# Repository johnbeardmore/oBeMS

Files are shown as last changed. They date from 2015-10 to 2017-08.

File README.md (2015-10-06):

oBeMS
=====

Open source environmental monitoring, automatic meter reading and building management system.

Note that the items in [square brackets] below are planned, but not yet implemented.

Open Source GPL2 system for energy and environmental measurement, automatic meter reading (AMR), [building energy management (BEMS), and building management (BMS)].

The system consists of server processes which provide access to sensors and actuators via IP address and port number. Server processes are used which provide user interfaces, [make BMS and BEMS decisions], and relay information to archival stores.

An archival store is provided to record environmental conditions, [and BMS and BEMS decisions].

Modules can be distributed around the internet, and in this sense it may be seen as part of the Internet Of Things (IoT).

Initial development has mostly taken place on the Raspberry Pi under Raspbian, though it should port perfectly well to other linux based boards, e.g. the BeagleBone.

The archival database has been implemented on an Intel Linux box to avoid doing frequent writes to SD cards.

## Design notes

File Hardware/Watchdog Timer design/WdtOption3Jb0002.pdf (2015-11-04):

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

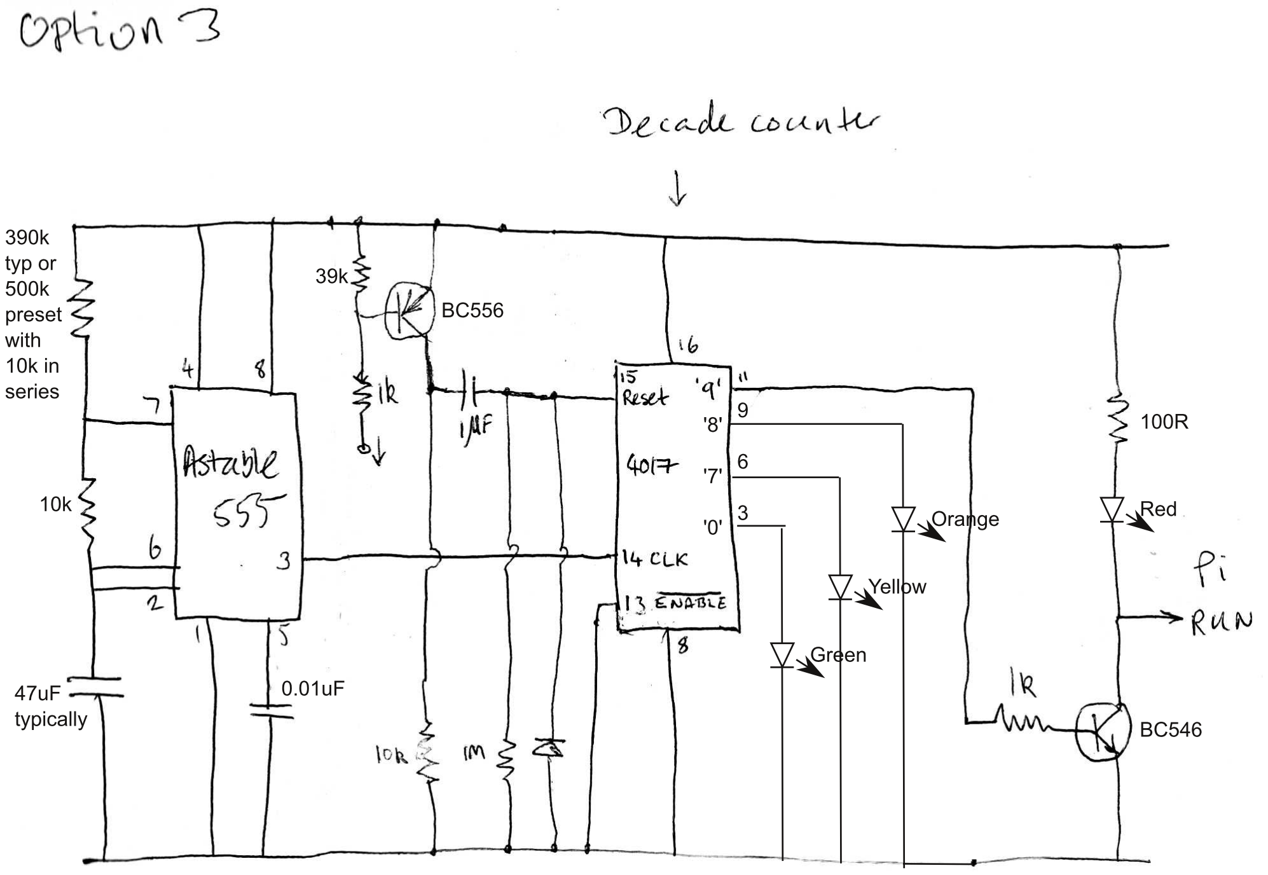
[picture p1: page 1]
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

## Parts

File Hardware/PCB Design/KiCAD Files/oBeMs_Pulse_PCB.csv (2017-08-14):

Reference | Quantity | Value | Footprint | Datasheet | Description | Manufacturer | Manufacturer Part No | Supplier 1 | Supplier 1 Part No | Notes | Supplier 2 | Supplier 2 Part No
C1 C10 | 2 | 100u | REInnovationFootprint:C2V8_VandA |  | Value | Value | Value | Value | Value | Value | Value | Value
C11 C2 | 2 | 1000u | REInnovationFootprint:C2V8_VandA |  | Value | Value | Value | Value | Value | Value | Value | Value
C3 | 1 | 1u | matts_components:C1_wide_lg_pad_2
C4 | 1 | 0.1u | matts_components:C1_wide_lg_pad_2
C5 | 1 | 10n | matts_components:C1_wide_lg_pad_2
C6 | 1 | 47u | REInnovationFootprint:C2V8_VandA
C7 C8 | 2 | 1000n | matts_components:C1_wide_lg_pad_2 |  | Value | Value | Value | Value | Value | Value | Value | Value
C9 | 1 | 100n | matts_components:C1_wide_lg_pad_2 |  | Value | Value | Value | Value | Value | Value | Value | Value
CPU1 | 1 | RPi_B | REInnovationFootprint:RPi_B_B+_MOUNTING
D12 | 1 | GRN | REInnovationFootprint:LED-5MM_larg_pad
D13 | 1 | YEL | REInnovationFootprint:LED-5MM_larg_pad |  | Value | Value | Value | Value | Value | Value | Value | Value
D14 | 1 | ORG | REInnovationFootprint:LED-5MM_larg_pad
D1 D15 | 2 | 1N5822 | REInnovationFootprint:TH_Diode_DO-201AD |  | 3A 40V Shottky Diode | STMicroelectronics | 1N5822 | RS | 687-0877
D16 | 1 | BRIDGE | REInnovationFootprint:TH_BridgeRect_8A | http://docs-europe.electrocomponents.com/webdocs/1404/0900766b81404e75.pdf | 8A Bridge Rectifier | Taiwan Semiconductor | KBU807G | RS | 687-5914
D2 | 1 | 1N4001 | REInnovationFootprint:TH_Diode_1
D3 | 1 | RED | REInnovationFootprint:LED-5MM_larg_pad
D10 D11 D4 D5 D6 D7 D8 D9 | 8 | LED | REInnovationFootprint:LED-5MM_larg_pad
EN1 | 1 | Enclosure
F1 | 1 | 500mA | REInnovationFootprint:TH_Fuse_Holder_5-20_CPC | http://www.farnell.com/datasheets/1564551.pdf | 240V AC 5A Fuseholder | Unbranded | MCHTC-100M | CPC | FF01942
H1 H2 | 2 | AC Cover Mount Hole | REInnovationFootprint:3mm_hole
L1 | 1 | 330uH | REInnovationFootprint:TH_Inductor | http://docs-europe.electrocomponents.com/webdocs/0d90/0900766b80d90b31.pdf | Inductor. 1A RMS. | Panasonic | ELC11D331F | RS | 675-5428
L2 | 1 | 100uH | REInnovationFootprint:TH_Inductor_ELC18B101L | http://docs-europe.electrocomponents.com/webdocs/002b/0900766b8002b270.pdf | Inductor. 3A RMS. | Panasonic | ELC18B101L | RS | 233-5409
LG1 | 1 | REI Logo | matts_components:reinnovation_logo_15mm
LG2 | 1 | T4 Logo | PCB_logo:T4_32mm
LG3 | 1 | OSHW Logo | PCB_logo:OSHW_13mm
LG4 | 1 | V0000 |  |  | Value | Value | Value | Value | Value | Value | Value | Value
P1 | 1 | 1WIRE | REInnovationFootprint:Pin_Header_Straight_1x04
P10 | 1 | 5V | REInnovationFootprint:Pin_Header_Straight_2x08
P11 | 1 | 3V3 | REInnovationFootprint:Pin_Header_Straight_2x08
P12 | 1 | GND | REInnovationFootprint:Pin_Header_Straight_2x08
P13 | 1 | ADC_0-7 | REInnovationFootprint:Pin_Header_Straight_2x08
P14 | 1 | ADC_8-15 | REInnovationFootprint:Pin_Header_Straight_2x08
P15 | 1 | ADC_VREF_2 | REInnovationFootprint:Pin_Header_Straight_1x02
P16 | 1 | ADC_VREF_1 | REInnovationFootprint:Pin_Header_Straight_1x02
P17 | 1 | SPI_ADC_DAC | REInnovationFootprint:Pin_Header_Straight_1x08
P18 P22 P26 | 3 | DIO_OUTPUT | REInnovationFootprint:Pin_Header_Straight_2x12
P19 P23 P27 | 3 | PULL_UP | REInnovationFootprint:Pin_Header_Straight_2x12
P2 | 1 | EXT_CAP | matts_components:SIL-2_wide_lg_pad
P20 P24 P28 | 3 | GROUND | REInnovationFootprint:Pin_Header_Straight_2x12
P21 P25 P29 | 3 | DIO_INPUT | REInnovationFootprint:HEADER_12Way_Wiedermuller_SX | http://docs-europe.electrocomponents.com/webdocs/0fdb/0900766b80fdbcf2.pdf | 12 Way Pluggable Connector. SL 5.08 Series | Wiedermuller | 1511360000 | CPC | CN12535
P3 | 1 | HARD_WDT | REInnovationFootprint:TH_4x1_CONN
P30 | 1 | UNREG_DC | REInnovationFootprint:Pin_Header_Straight_2x03
P31 | 1 | V2? | REInnovationFootprint:SIL-3_solder_connect
P34 | 1 | DAC | REInnovationFootprint:Pin_Header_Straight_2x04
P36 | 1 | PROTOTYPING_AREA | REInnovationFootprint:PROTO_AREA_16x14
P4 | 1 | LED 5-8 | REInnovationFootprint:Pin_Header_Straight_1x04
P5 | 1 | AC_INPUT_PLUG |  | http://www.farnell.com/datasheets/1826287.pdf | 240V AC >3A PLUG | CamdenBoss | CTB9208/3 | CPC | CN11606
P6 | 1 | AC_INPUT | REInnovationFootprint:TH_3W_CamdenBoss | http://www.farnell.com/datasheets/1564536.pdf | 240V AC >3A | CamdenBoss | CTB9358/3 | CPC | CN11626
P7 | 1 | LED 1-4 | REInnovationFootprint:Pin_Header_Straight_1x04
P8 | 1 | LT_PWR | REInnovationFootprint:TH_CONN_2W
P9 | 1 | V1? | REInnovationFootprint:SIL-3_solder_connect
PCB1 | 1 | PCB | REInnovationFootprint:PCB_120x150_WISKA
PSU1 | 1 | PSU_10W_5V | REInnovationFootprint:TH_DCDC_PowerPac_5W_10W | http://www.farnell.com/datasheets/1683226.pdf | 240V AC to 5V PSU 5/10W 1/2A | Powerpax | PD05-20B05 | CPC | PW03300
Q1 | 1 | BC546 | matts_components:TO92-EBC_large_pad | http://docs-europe.electrocomponents.com/webdocs/078e/0900766b8078ea72.pdf | NPN. 1A. 80V | ON Semiconductor | BC639 | RS | 545-2276
Q2 | 1 | BC556 | matts_components:TO92-PNP_large_pad
R1 | 1 | 4k7 | REInnovationFootprint:TH_Resistor_1
R11 R12 R13 R14 R15 R16 R17 R18 R19 R20 R21 R22 R23 R24 R25 R26 R27 R28 R29 R30 R31 R32 R33 R34 R35 R36 R37 R38 R39 R40 R41 R42 R43 R44 R45 R46 R47 R48 R49 R50 R51 R52 R53 R54 | 44 | 120 | REInnovationFootprint:TH_Resistor_1 |  | Value | Value | Value | Value | Value | Value | Value | Value
R3 | 1 | 1M | REInnovationFootprint:TH_Resistor_1
R4 R7 | 2 | 1k | REInnovationFootprint:TH_Resistor_1
R5 | 1 | 39k | REInnovationFootprint:TH_Resistor_1
R6 | 1 | 100 | REInnovationFootprint:TH_Resistor_1 |  | Value | Value | Value | Value | Value | Value | Value | Value
R2 R8 R9 | 3 | 10k | REInnovationFootprint:TH_Resistor_1
RV1 | 1 | 500k | matts_components:RV_various_lg_pad
U1 | 1 | LM2575 | REInnovationFootprint:TO220_5PIN | http://docs-europe.electrocomponents.com/webdocs/0780/0900766b807800ee.pdf | 1A 3.3V DC DC converter IC | Texas Instruments | LM2575T-3.3/NOPB | RS | 533-3169
U2 | 1 | DS18B20 | REInnovationFootprint:TO92_DS18B20 | https://uk.rs-online.com/web/p/temperature-humidity-sensors/7860809/ | 1 Wire. Serial. Temperature sensor | Maxim | DS18B20+PAR | RS | 786-0809
U3 | 1 | TLC555 | REInnovationFootprint:DIP-8__300_ELL
U4 | 1 | 4017 | REInnovationFootprint:DIP-16__300_ELL_lg_pad
U5 U6 | 2 | MCP3008 | REInnovationFootprint:DIP-16__300_ELL_lg_pad
U7 | 1 | MCP4802 | REInnovationFootprint:DIP-8_300_ELL | http://ww1.microchip.com/downloads/en/DeviceDoc/22249A.pdf | 8 Bit Dual DAC | Microchip
U8 | 1 | LM2576 | REInnovationFootprint:TO220_5PIN | http://www.ti.com/lit/ds/symlink/lm2576.pdf |  | Texas Instruments | LM2576T-5.0/LF03 | RS | 460-477 | 3A step-down DC DC converter 5V

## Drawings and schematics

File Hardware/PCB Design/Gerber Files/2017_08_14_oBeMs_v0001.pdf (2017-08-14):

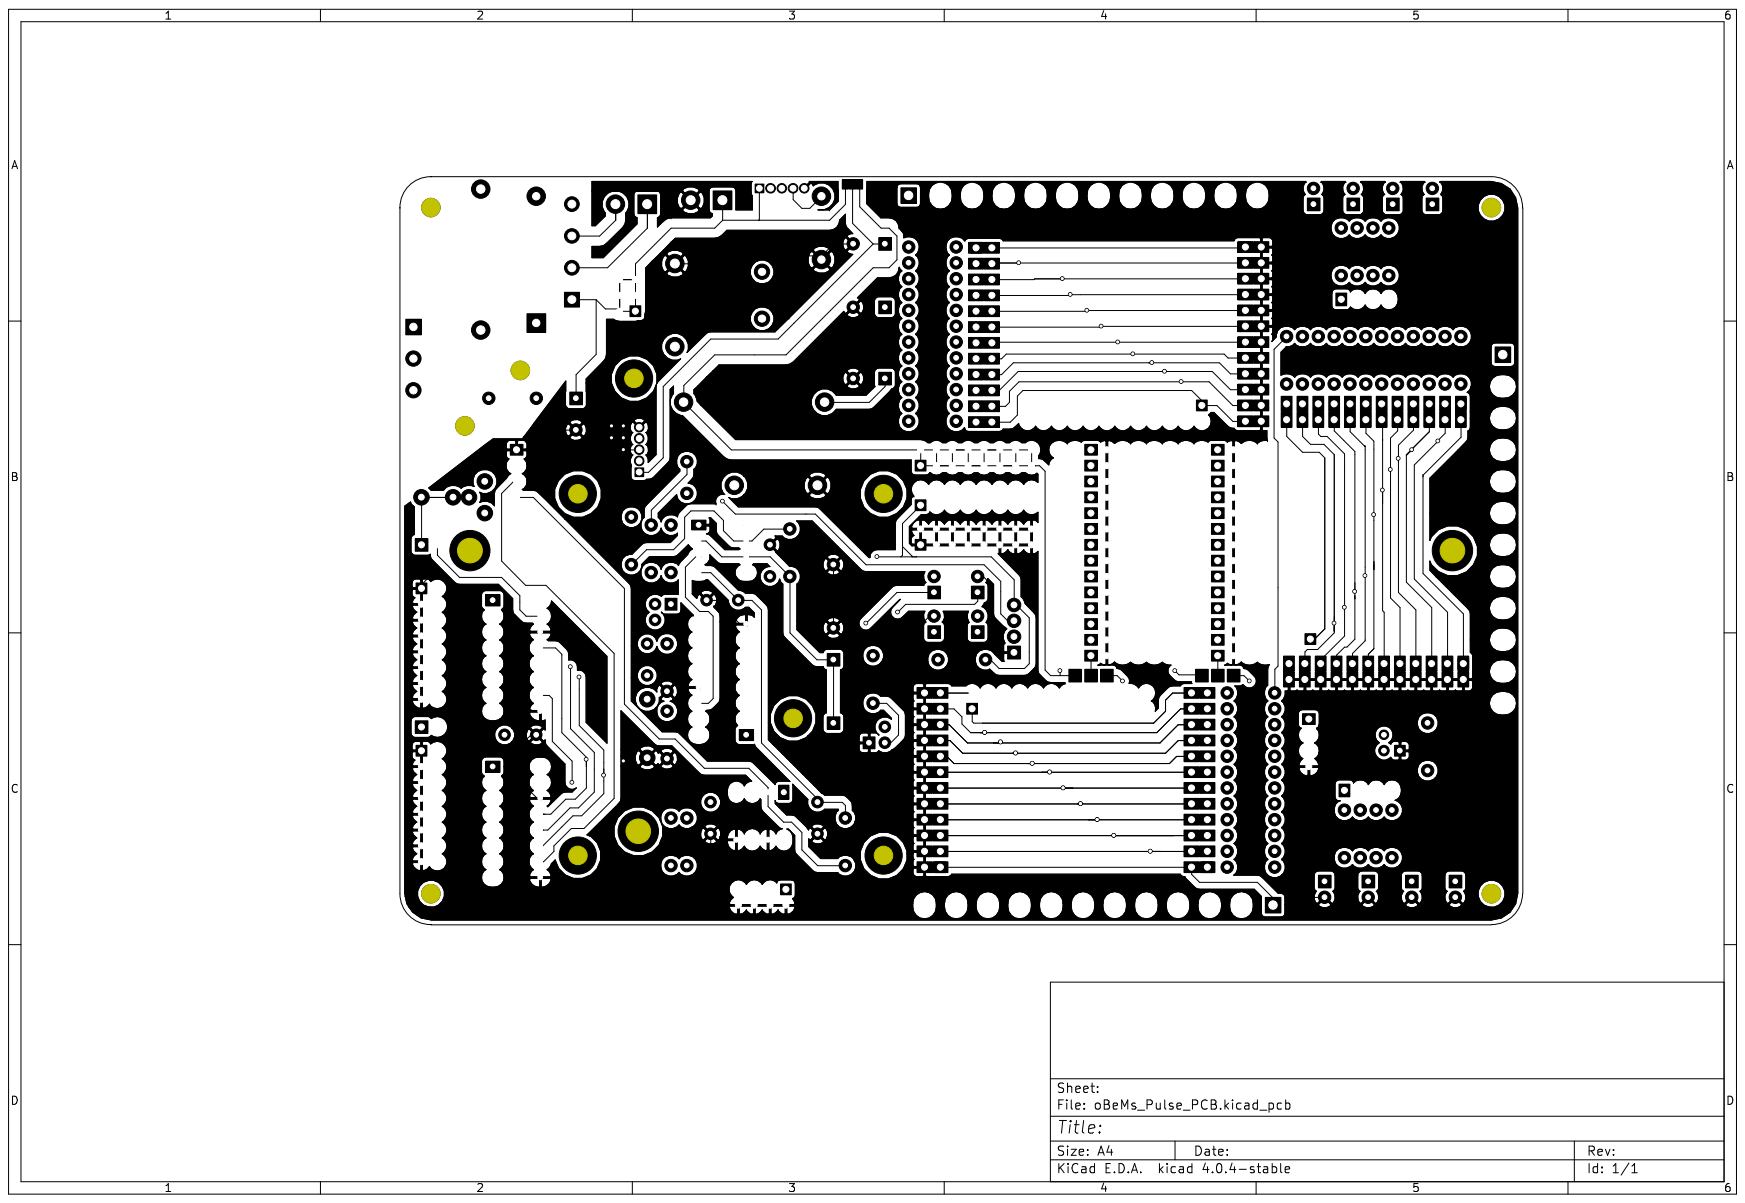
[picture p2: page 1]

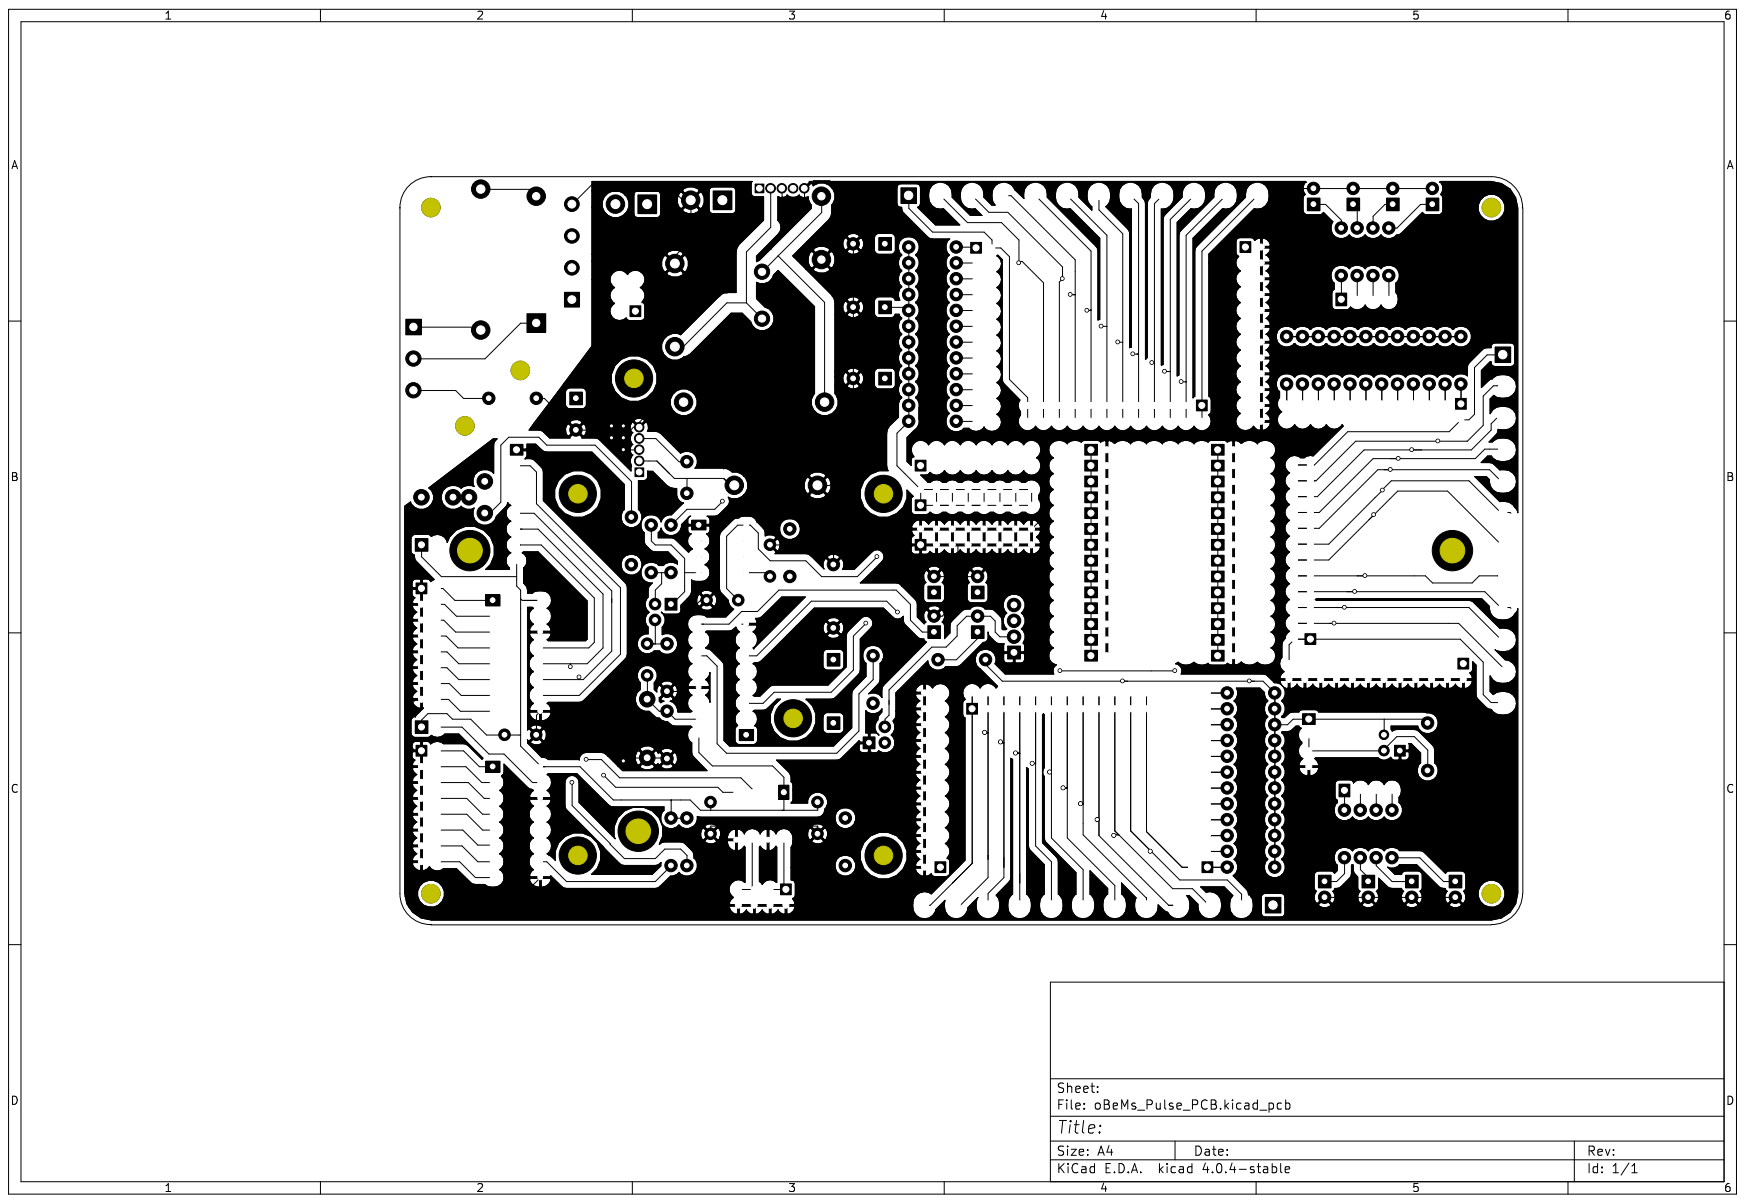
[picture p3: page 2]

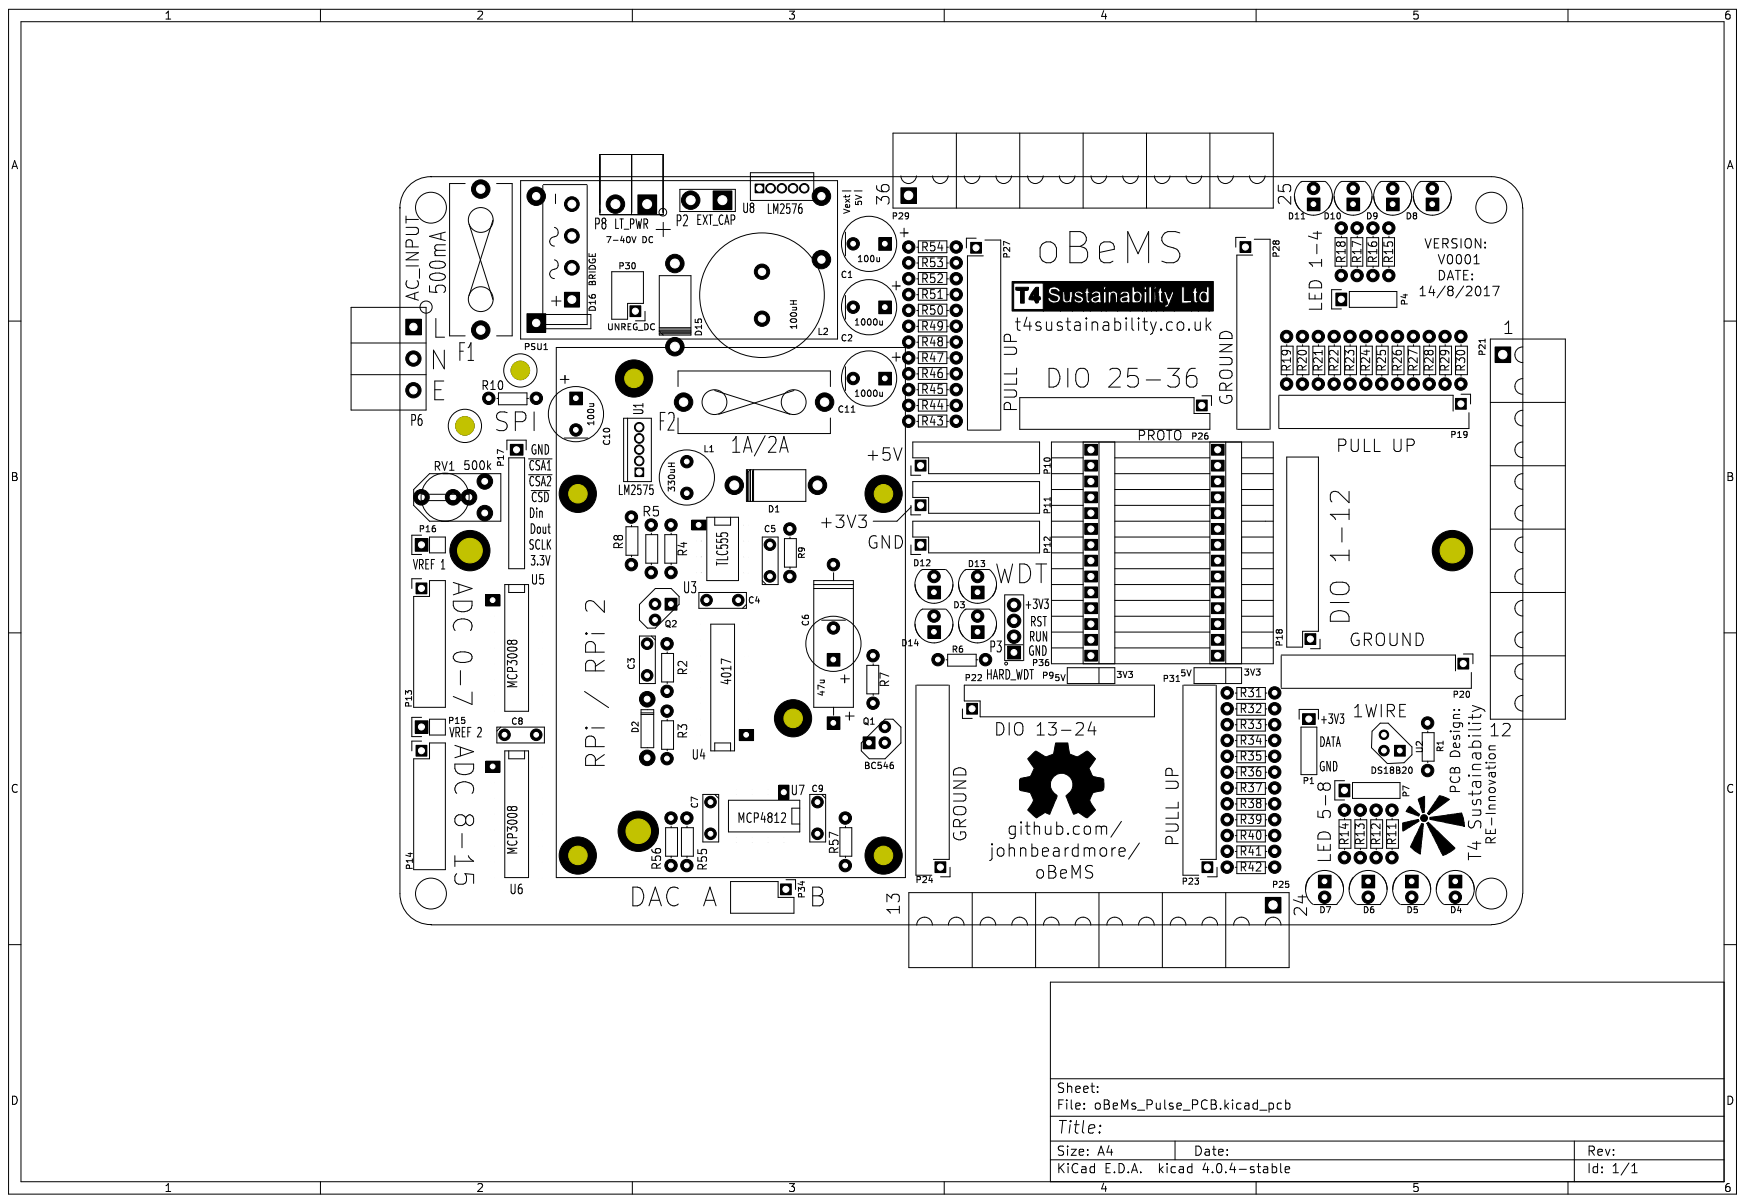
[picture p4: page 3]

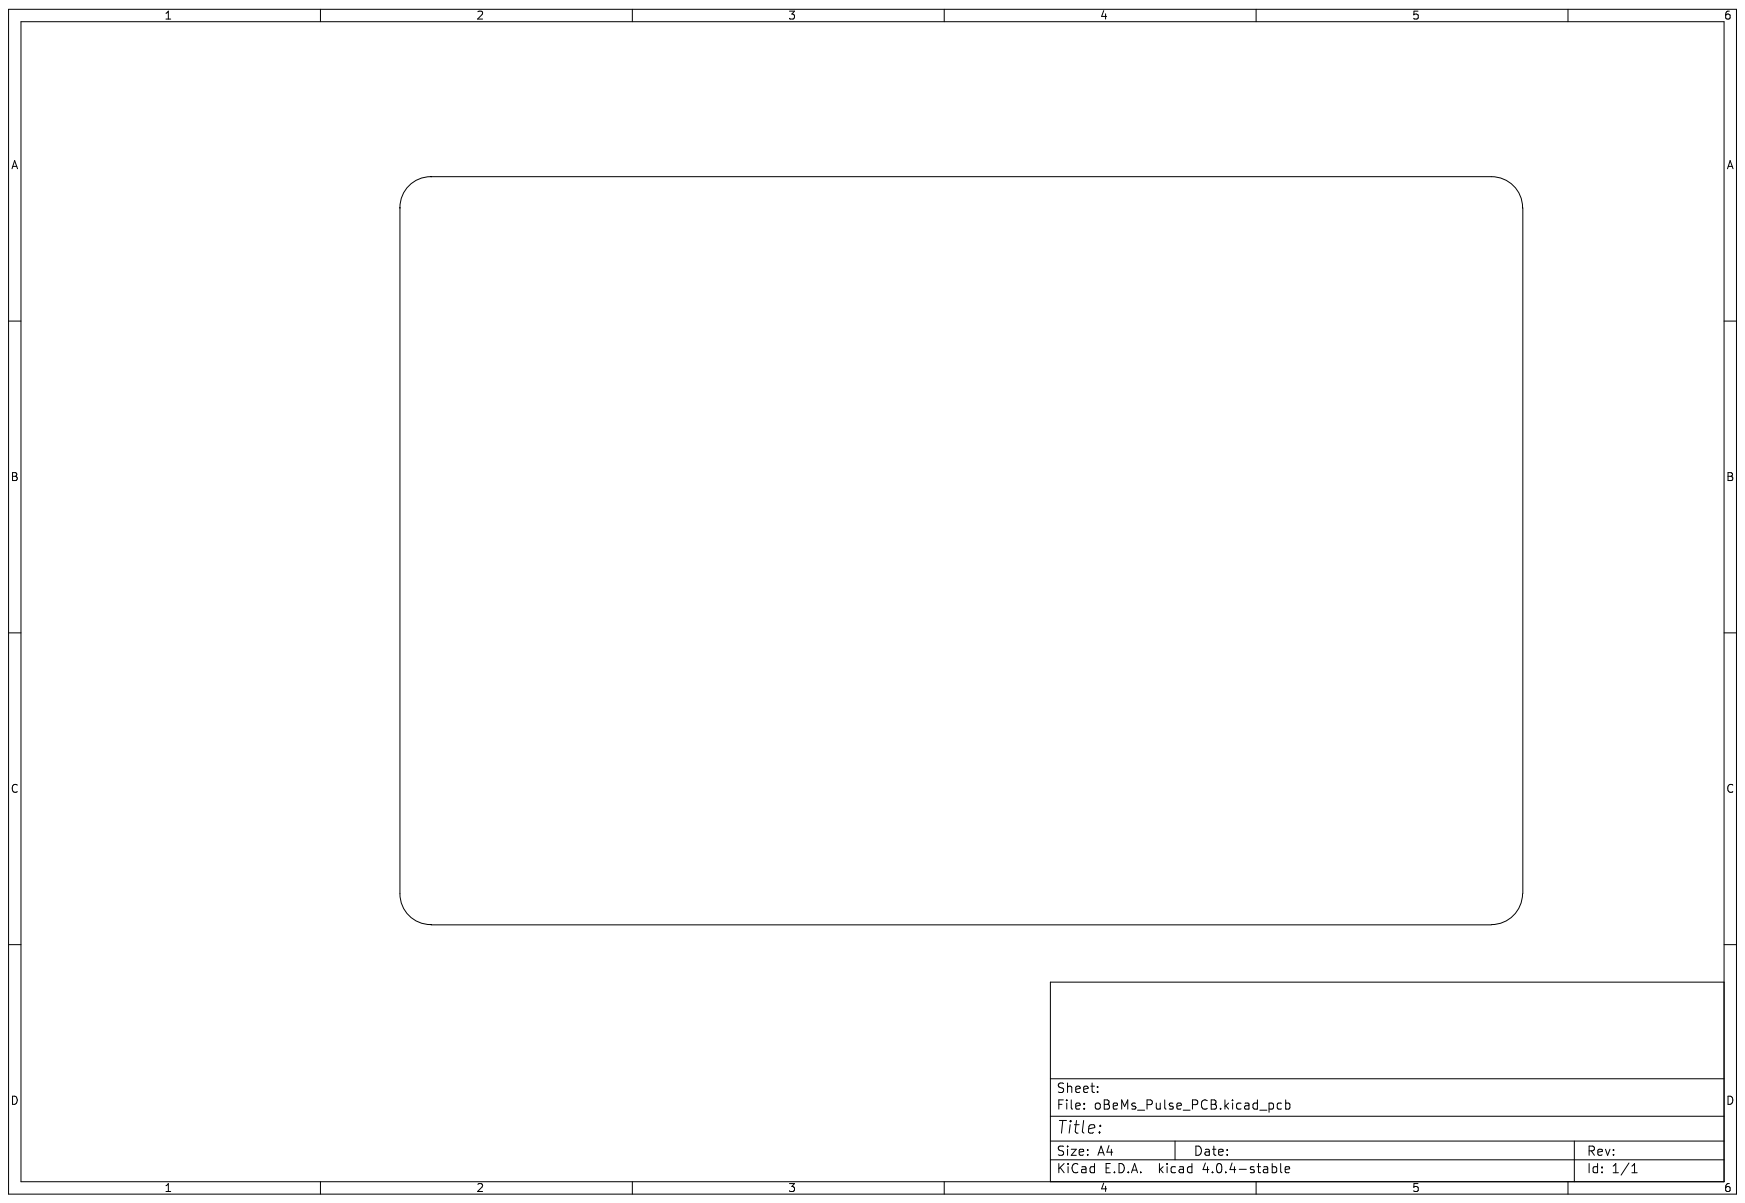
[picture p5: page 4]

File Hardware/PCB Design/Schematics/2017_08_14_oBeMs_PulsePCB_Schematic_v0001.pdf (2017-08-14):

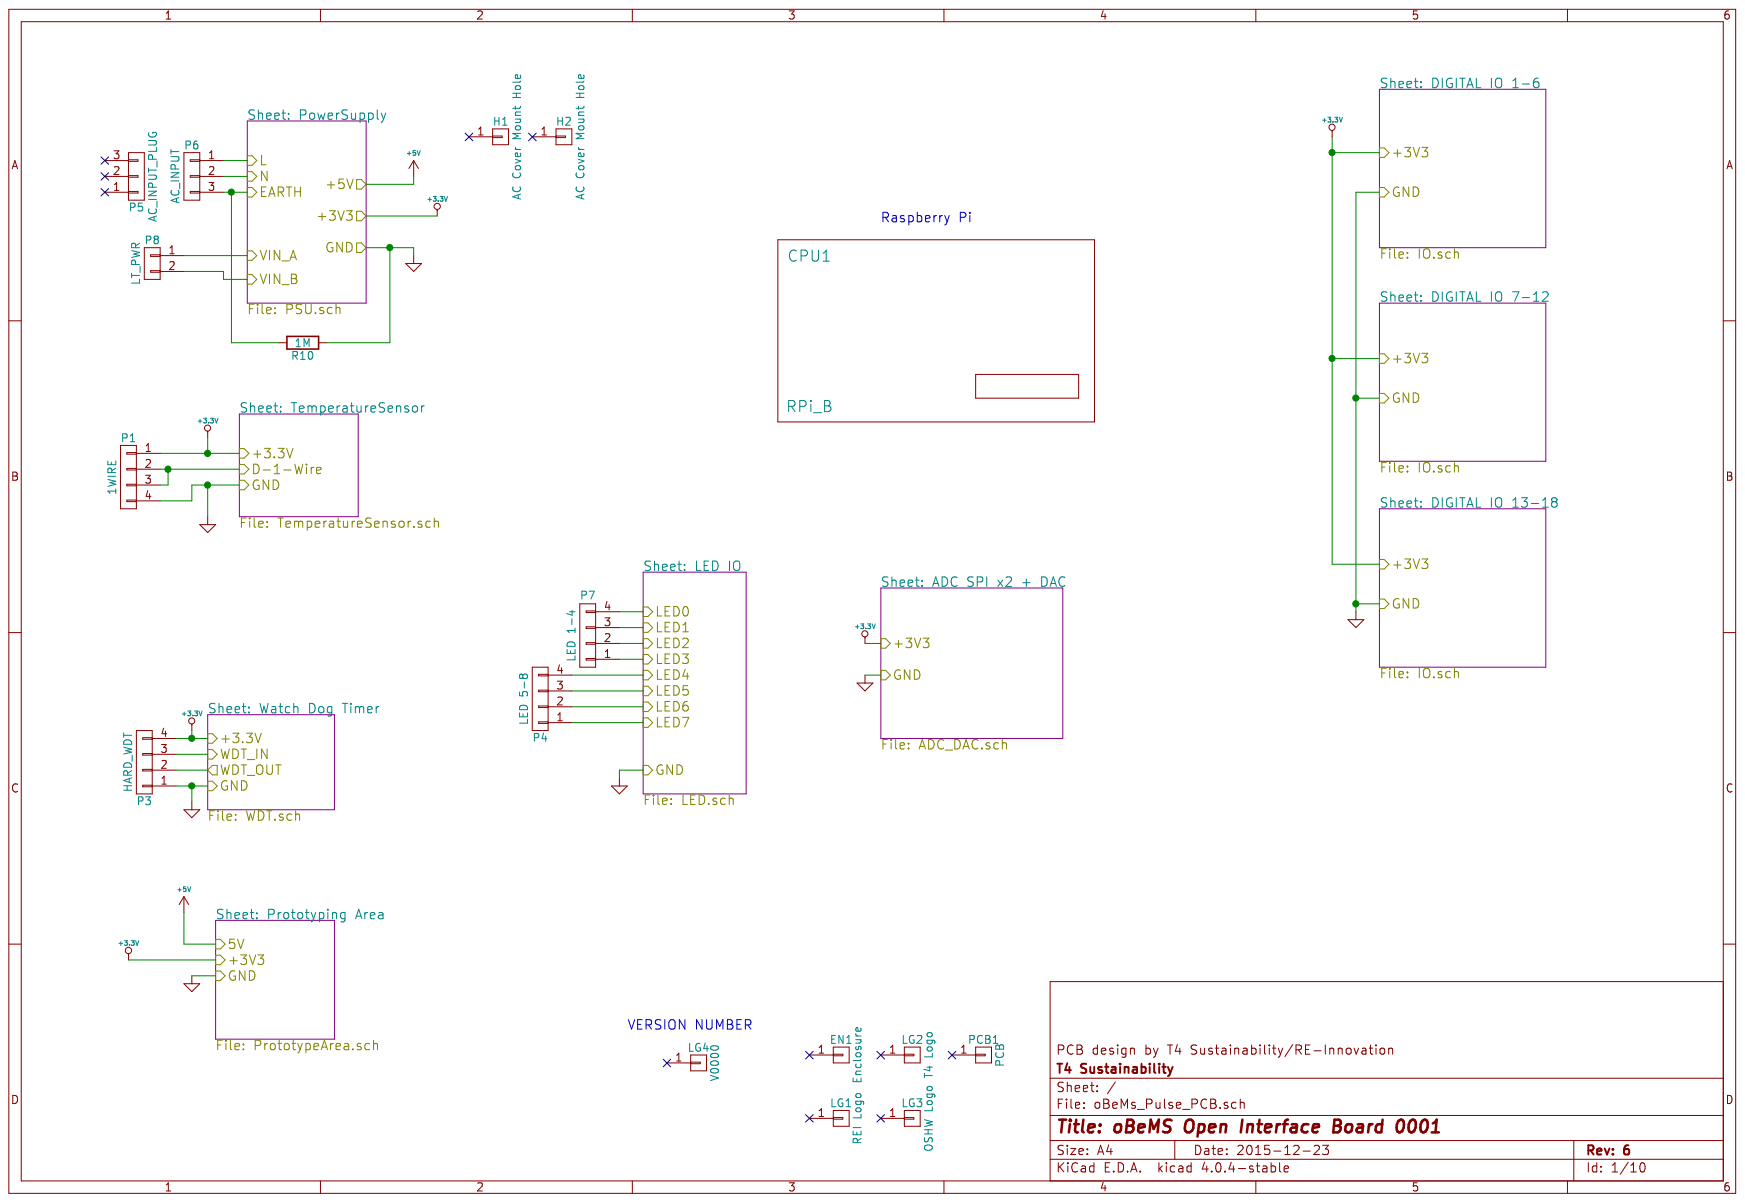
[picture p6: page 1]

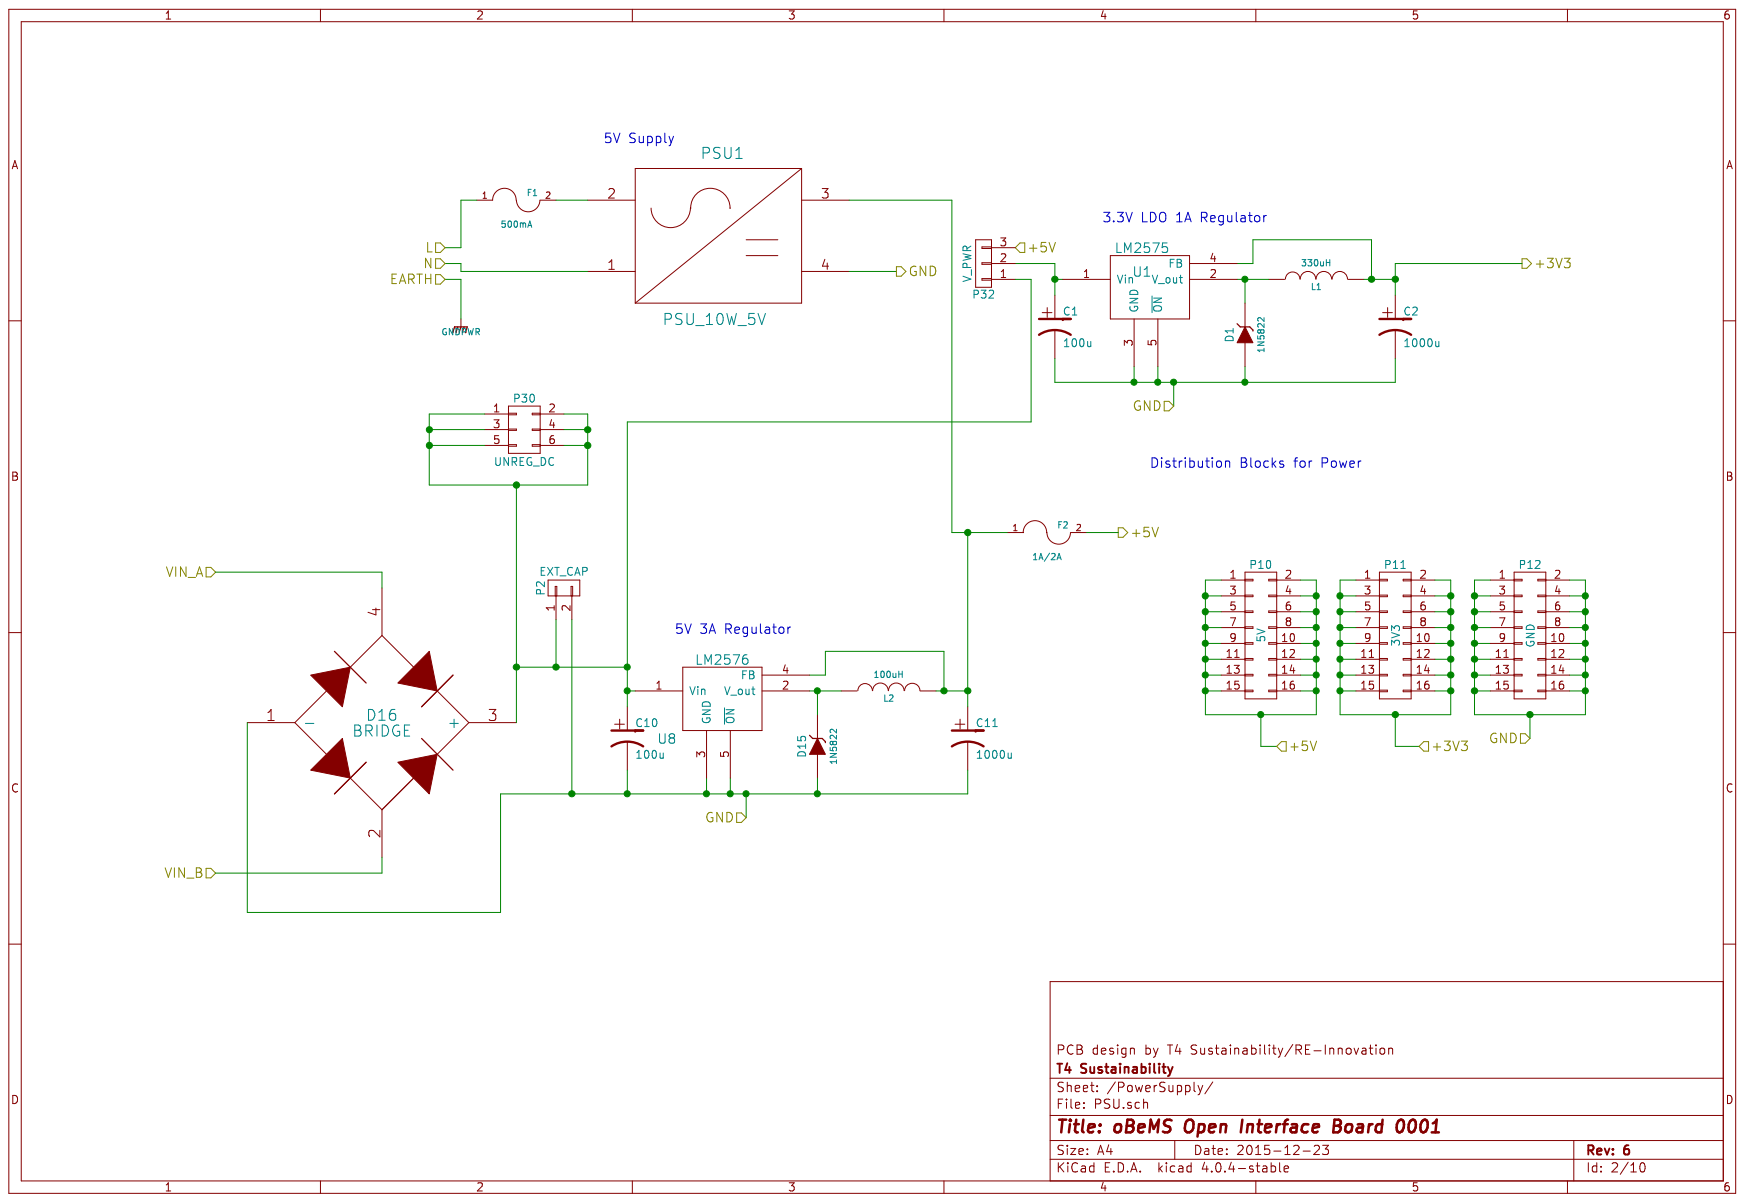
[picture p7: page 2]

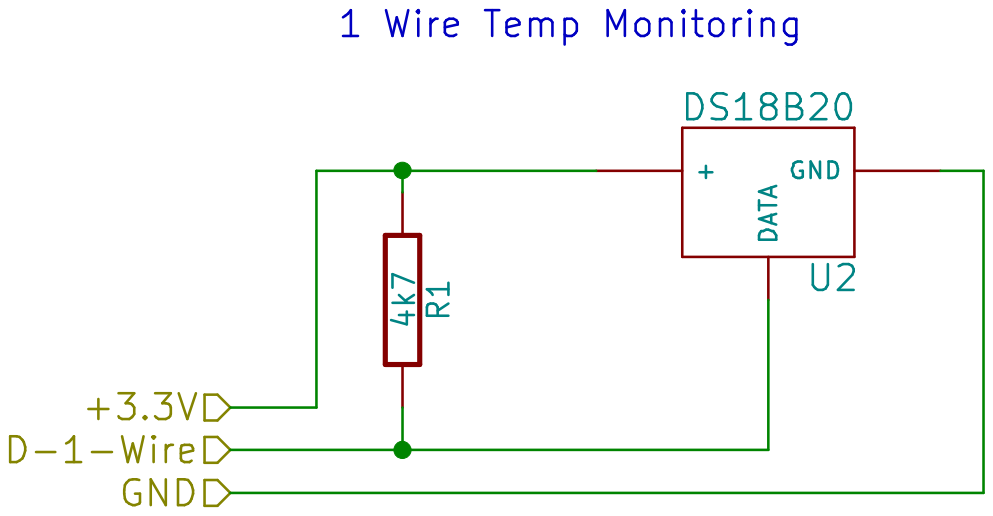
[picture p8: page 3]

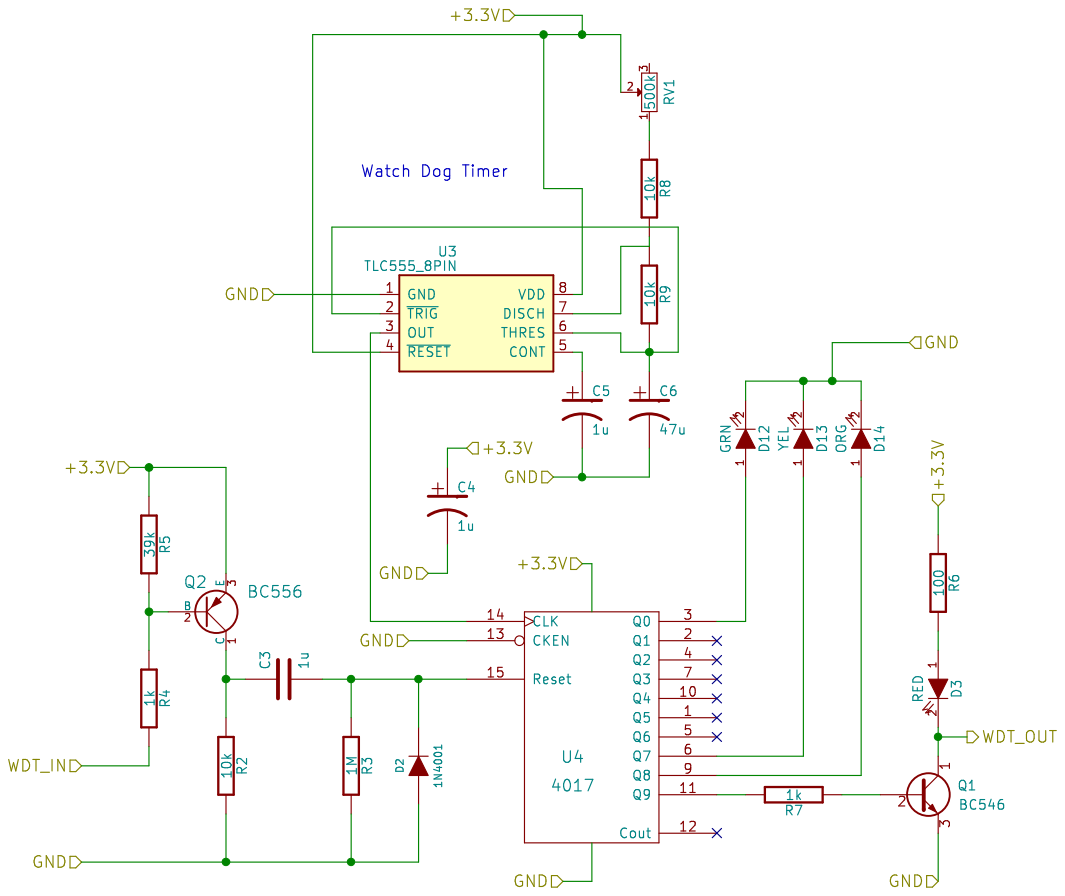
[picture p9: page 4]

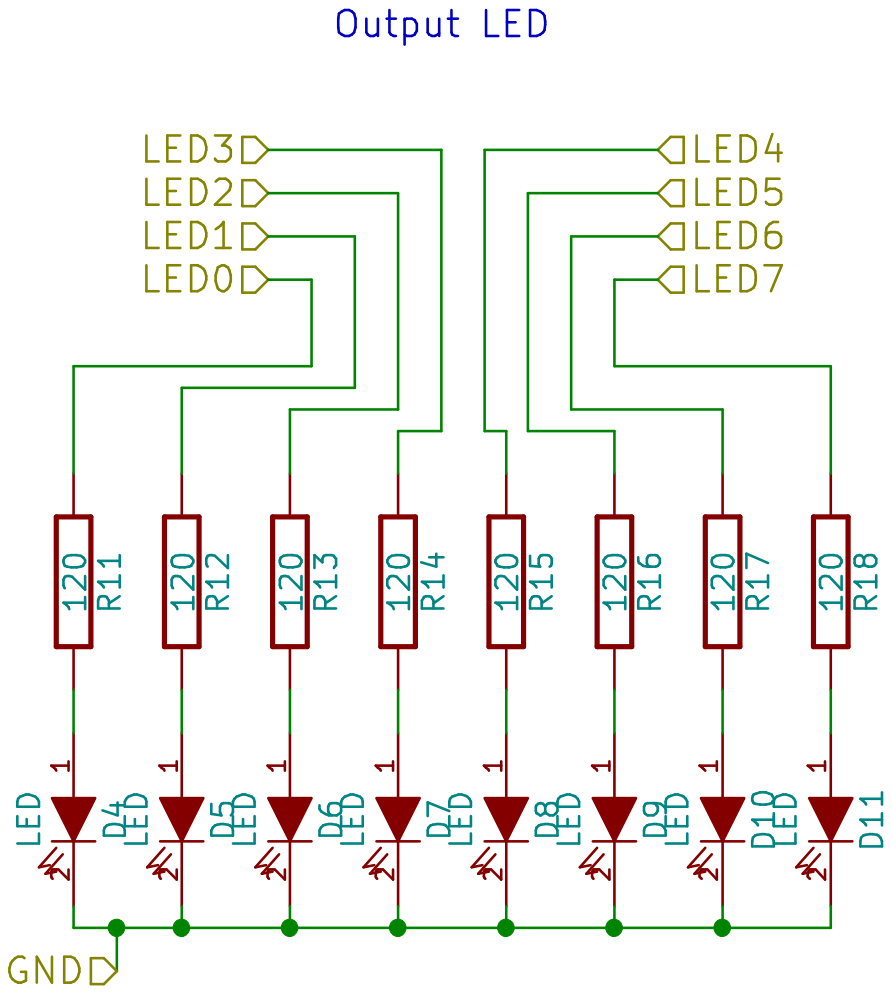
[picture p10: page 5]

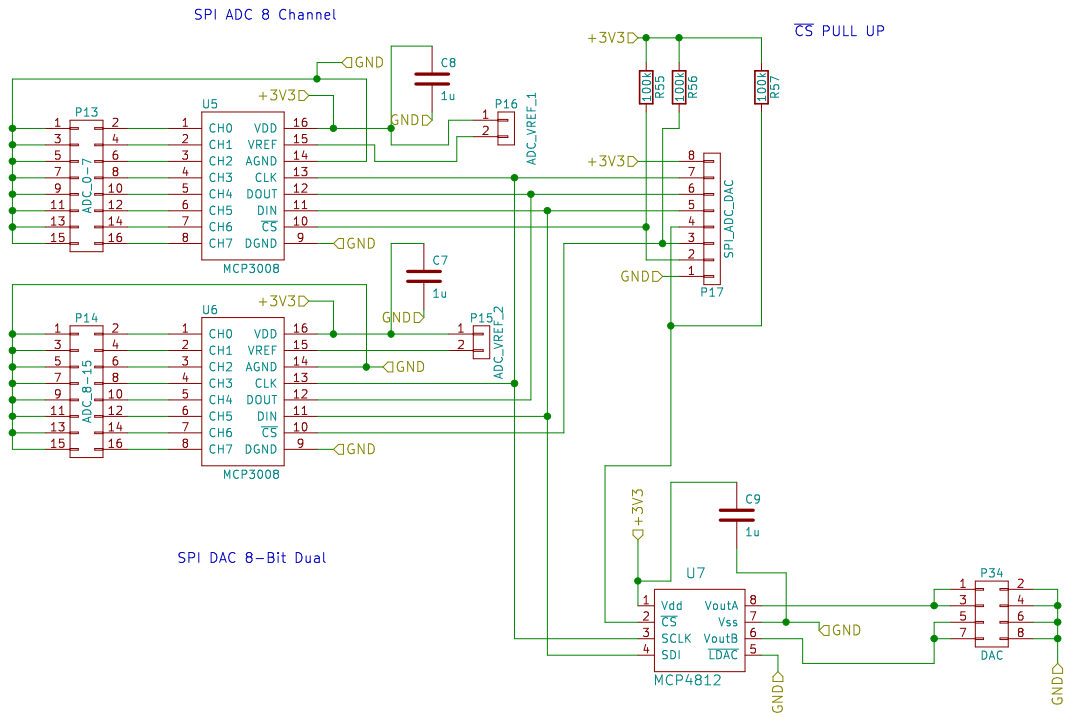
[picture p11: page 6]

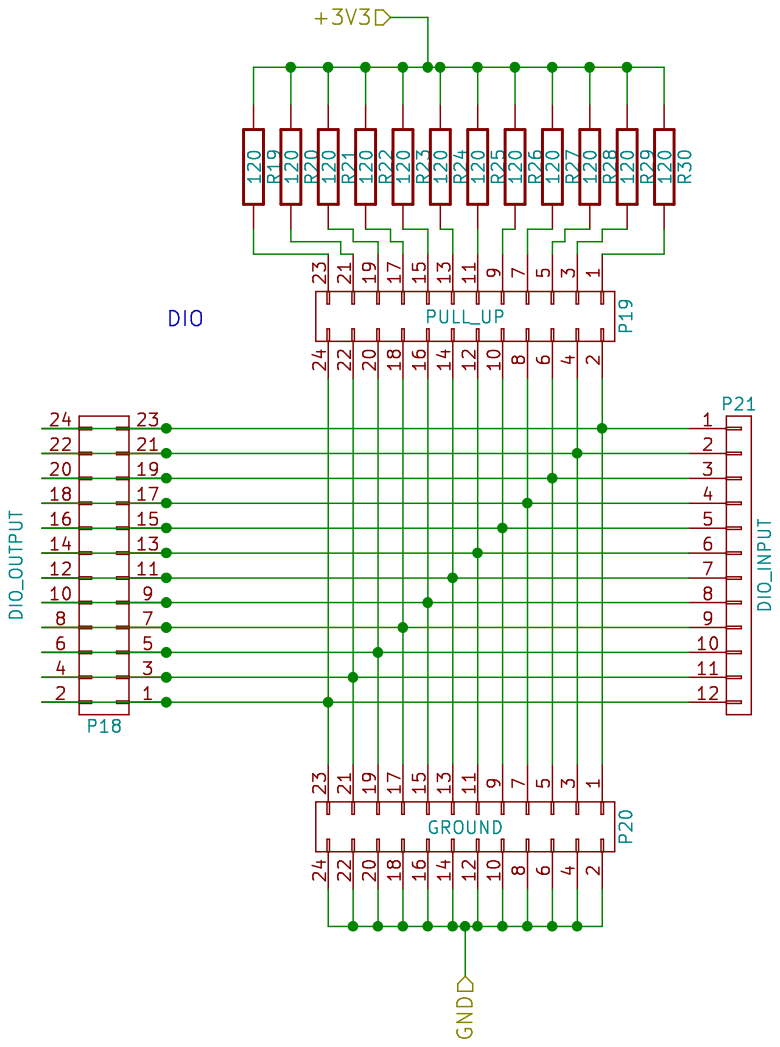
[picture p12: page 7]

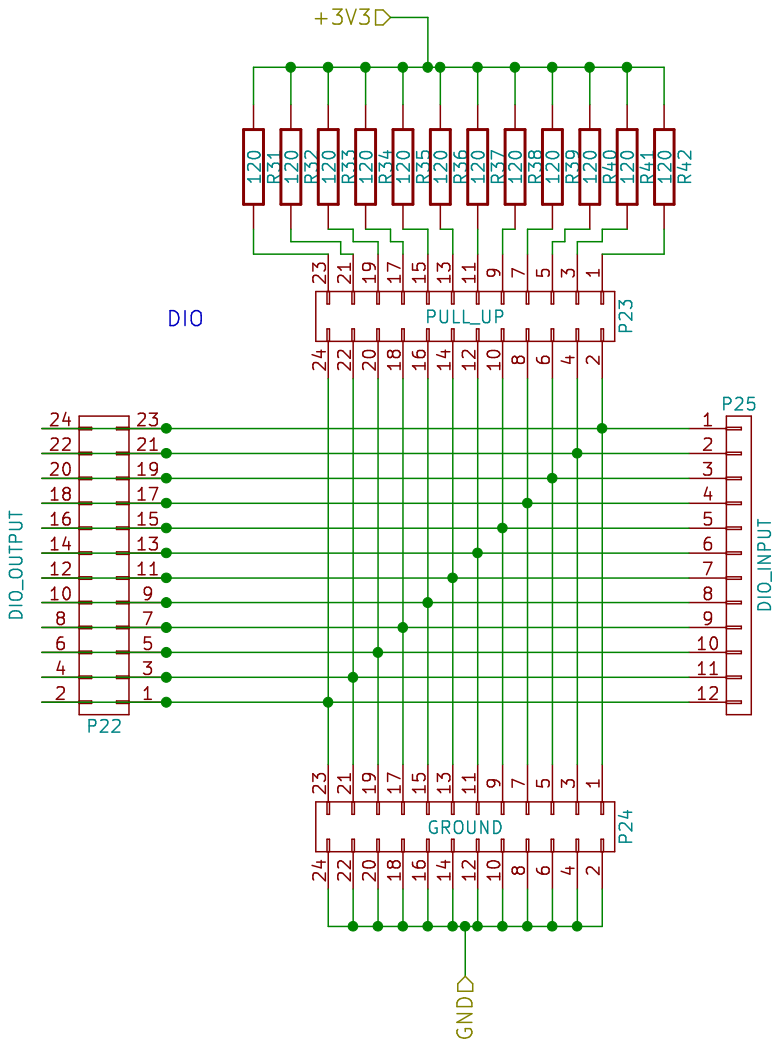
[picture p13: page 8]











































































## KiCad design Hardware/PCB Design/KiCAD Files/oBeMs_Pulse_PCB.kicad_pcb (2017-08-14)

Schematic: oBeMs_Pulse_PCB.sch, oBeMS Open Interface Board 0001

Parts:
CPU1: RPi_B; RPi_B_B+_MOUNTING
EN1: Enclosure
H1, H2: AC Cover Mount Hole; 3mm_hole
LG1: REI Logo; reinnovation_logo_15mm
LG2: T4 Logo; T4_32mm
LG3: OSHW Logo; OSHW_13mm
LG4: V0000; Manufacturer Part No Value
P1: 1WIRE; Pin_Header_Straight_1x04
P3: HARD_WDT; TH_4x1_CONN
P4: LED 5-8; Pin_Header_Straight_1x04
P5: AC_INPUT_PLUG; Manufacturer Part No CTB9208/3
P6: AC_INPUT; TH_3W_CamdenBoss; Manufacturer Part No CTB9358/3
P7: LED 1-4; Pin_Header_Straight_1x04
P8: LT_PWR; TH_CONN_2W_LGPAD
PCB1: PCB; PCB_120x150_WISKA
R10: 1M; TH_Resistor_1

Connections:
/LED IO/LED0: P7.4; also elsewhere on the board
/LED IO/LED1: P7.3; also elsewhere on the board
/LED IO/LED2: P7.2; also elsewhere on the board
/LED IO/LED3: P7.1; also elsewhere on the board
/LED IO/LED4: P4.4; also elsewhere on the board
/LED IO/LED5: P4.3; also elsewhere on the board
/LED IO/LED6: P4.2; also elsewhere on the board
/LED IO/LED7: P4.1; also elsewhere on the board
/PowerSupply/L: P6.1; also elsewhere on the board
/PowerSupply/N: P6.2; also elsewhere on the board
/PowerSupply/VIN_A: P8.1; also elsewhere on the board
/PowerSupply/VIN_B: P8.2; also elsewhere on the board
/TemperatureSensor/D-1-Wire: P1.2, P1.3; also elsewhere on the board
/Watch Dog Timer/WDT_IN: P3.3; also elsewhere on the board
/Watch Dog Timer/WDT_OUT: P3.2; also elsewhere on the board
GNDPWR: P6.3, R10.2

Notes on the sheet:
Raspberry Pi
VERSION NUMBER

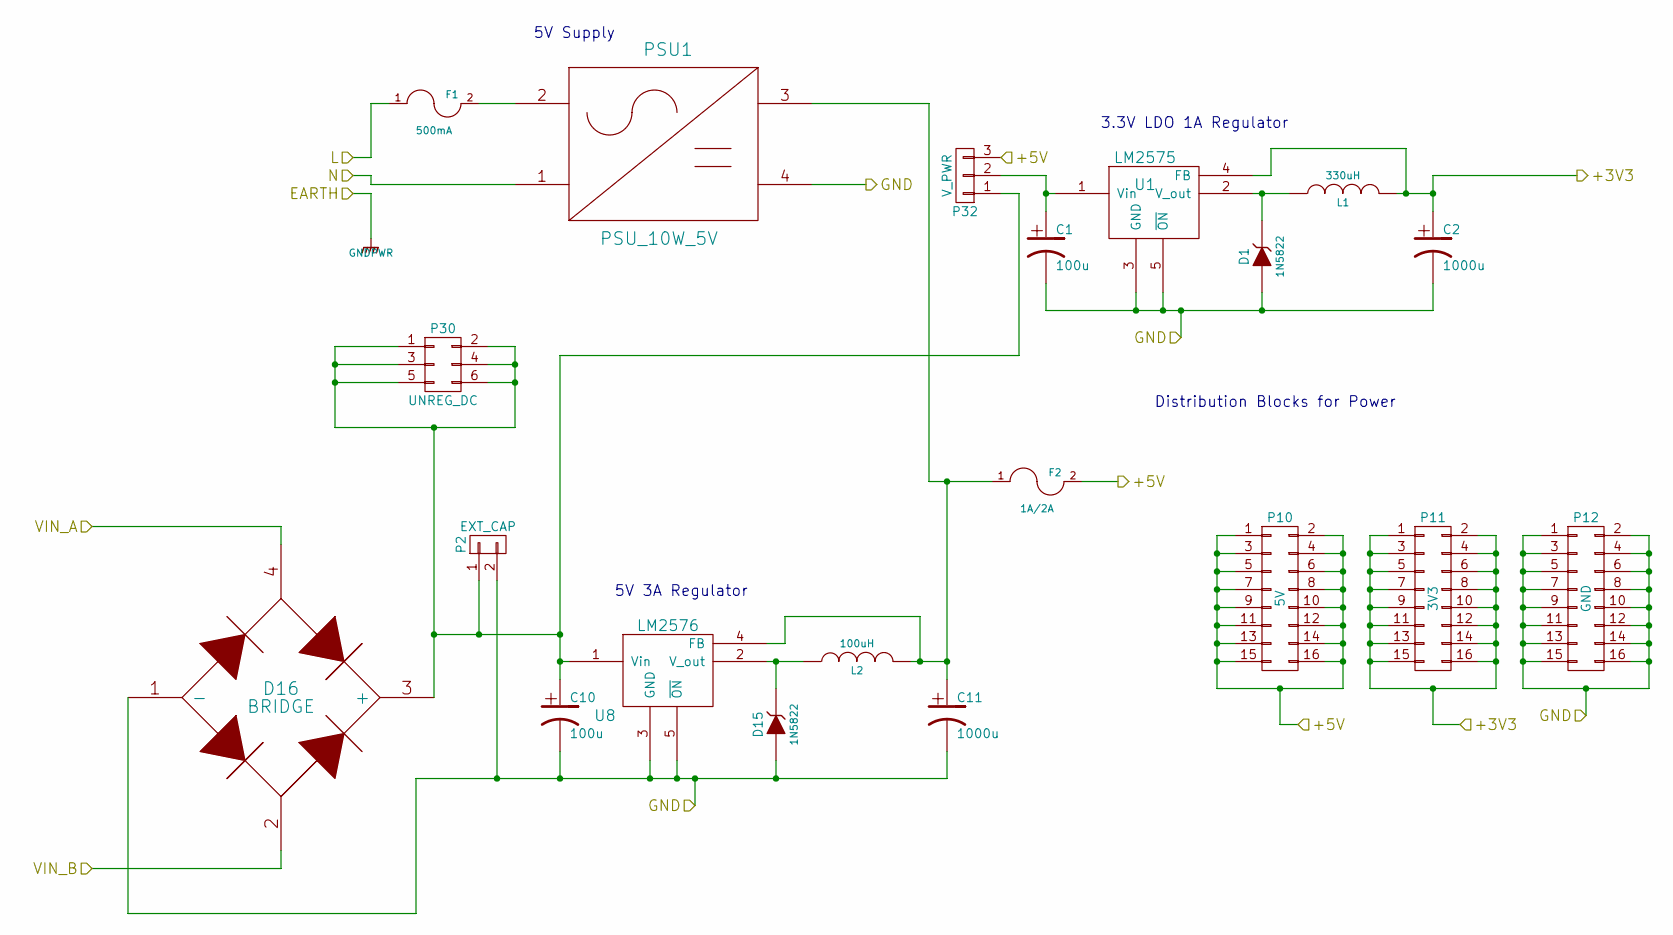
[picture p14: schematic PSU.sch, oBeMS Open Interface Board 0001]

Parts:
C1, C10: 100u; C2V8_V; Manufacturer Part No Value
C2, C11: 1000u; C2V8_V; Manufacturer Part No Value
D1, D15: 1N5822; TH_Diode_DO-201AD; Manufacturer Part No 1N5822
D16: BRIDGE; TH_BridgeRect_8A; Manufacturer Part No KBU807G
F1: 500mA; TH_Fuse_Holder_5-20_CPC; Manufacturer Part No MCHTC-100M
F2: 1A/2A; TH_Fuse_Holder_5-20_CPC; Manufacturer Part No MCHTC-100M
L1: 330uH; TH_Inductor; Manufacturer Part No ELC11D331F
L2: 100uH; TH_Inductor_ELC18B101L; Manufacturer Part No ELC18B101L
P2: EXT_CAP; SIL-2_LG_PAD
P10: 5V; Pin_Header_Straight_2x08
P11: 3V3; Pin_Header_Straight_2x08
P12: GND; Pin_Header_Straight_2x08
P30: UNREG_DC; Pin_Header_Straight_2x03
P32: V_PWR; SM_3pad_SOLDER_named
PSU1: PSU_10W_5V; TH_DCDC_PowerPac_5W_10W; Manufacturer Part No PD05-20B05
U1: LM2575; TO220_5PIN; Manufacturer Part No LM2575T-3.3/NOPB
U8: LM2576; TO220_5PIN; Manufacturer Part No LM2576T-5.0/LF03

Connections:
+5V: F2.2, P10.1, P10.2, P10.3, P10.4, P10.5, P10.6, P10.7, P10.8, P10.9, P10.10, P10.11, P10.12, P10.13, P10.14, P10.15, P10.16, P32.3; also elsewhere on the board
/PowerSupply/L: F1.1; also elsewhere on the board
/PowerSupply/N: PSU1.1 (N); also elsewhere on the board
/PowerSupply/VIN_A: D16.4; also elsewhere on the board
/PowerSupply/VIN_B: D16.2; also elsewhere on the board
unnamed: C1.1, P32.2, U1.1 (Vin)
unnamed: C10.1, D16.3 (+), P2.1, P30.1, P30.2, P30.3, P30.4, P30.5, P30.6, P32.1, U8.1 (Vin)
unnamed: C11.1, F2.1, L2.2, PSU1.3 (+5V), U8.4 (FB)
unnamed: D1.2 (K), L1.1, U1.2 (V_out)
unnamed: D15.2 (K), L2.1, U8.2 (V_out)
unnamed: F1.2, PSU1.2 (L)

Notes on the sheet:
5V Supply
3.3V LDO 1A Regulator
Distribution Blocks for Power
5V 3A Regulator

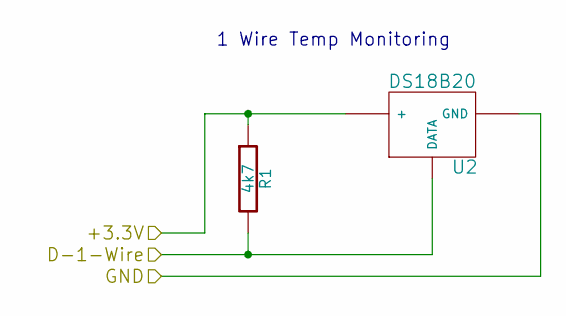
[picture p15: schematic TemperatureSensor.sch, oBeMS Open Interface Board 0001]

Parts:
R1: 4k7; TH_Resistor_1
U2: DS18B20; TO92_DS18B20; Manufacturer Part No DS18B20+PAR

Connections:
/TemperatureSensor/D-1-Wire: R1.2, U2.2 (DATA); also elsewhere on the board

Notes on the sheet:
1 Wire Temp Monitoring

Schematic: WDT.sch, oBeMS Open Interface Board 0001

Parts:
C3, C4, C5: 1u; C1_wide_lg_pad_2
C6: 47u; C2V8_VandA
D2: 1N4001; TH_Diode_1
D3: RED; LED-5MM_larg_pad
D12: GRN; LED-5MM_larg_pad
D13: YEL; LED-5MM_larg_pad; Manufacturer Part No Value
D14: ORG; LED-5MM_larg_pad
Q1: BC546; TO92-PNP_large_pad
Q2: BC556; TO92-PNP_large_pad
R2, R8, R9: 10k; TH_Resistor_1
R3: 1M; TH_Resistor_1
R4, R7: 1k; TH_Resistor_1
R5: 39k; TH_Resistor_1
R6: 100; TH_Resistor_1; Manufacturer Part No Value
RV1: 500k; RV_various_lg_pad
U3: TLC555_8PIN; DIP-8__300_ELL
U4: 4017; DIP-16__300_ELL_lg_pad

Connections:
/Watch Dog Timer/WDT_IN: R4.2; also elsewhere on the board
/Watch Dog Timer/WDT_OUT: D3.2 (K), Q1.1; also elsewhere on the board
unnamed: C3.1, Q2.1 (C), R2.1
unnamed: C3.2, D2.2 (K), R3.1, U4.15 (Reset)
unnamed: C5.1, U3.5
unnamed: C6.1, R9.2, U3.2, U3.6
unnamed: D3.1 (A), R6.2
unnamed: D12.1 (A), U4.3 (Q0)
unnamed: D13.1 (A), U4.6 (Q7)
unnamed: D14.1 (A), U4.9 (Q8)
unnamed: Q1.2, R7.1
unnamed: Q2.2 (B), R4.1, R5.2
unnamed: R7.2, U4.11 (Q9)
unnamed: R8.1, RV1.1
unnamed: R8.2, R9.1, U3.7
unnamed: U3.3, U4.14 (CLK)

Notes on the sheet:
Watch Dog Timer

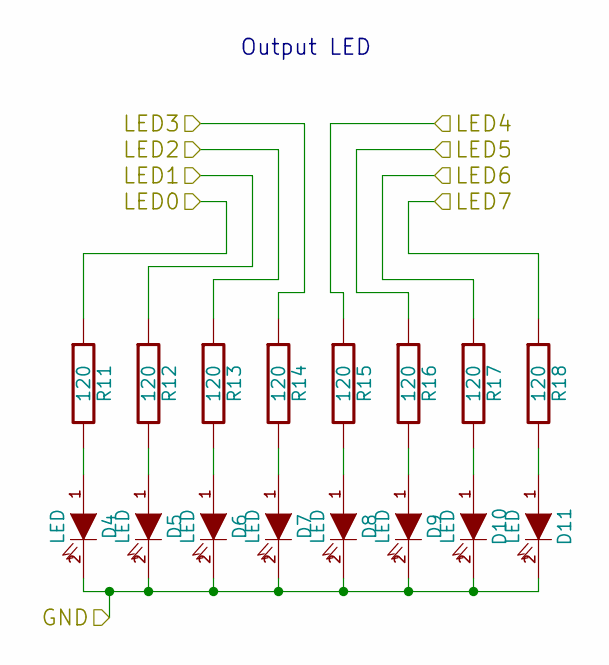
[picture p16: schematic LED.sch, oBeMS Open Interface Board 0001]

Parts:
D4, D5, D6, D7, D8, D9, D10, D11: LED; LED-5MM_larg_pad
R11, R12, R13, R14, R15, R16, R17, R18: 120; TH_Resistor_1; Manufacturer Part No Value

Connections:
/LED IO/LED0: R11.1; also elsewhere on the board
/LED IO/LED1: R12.1; also elsewhere on the board
/LED IO/LED2: R13.1; also elsewhere on the board
/LED IO/LED3: R14.1; also elsewhere on the board
/LED IO/LED4: R15.1; also elsewhere on the board
/LED IO/LED5: R16.1; also elsewhere on the board
/LED IO/LED6: R17.1; also elsewhere on the board
/LED IO/LED7: R18.1; also elsewhere on the board
unnamed: D4.1 (A), R11.2
unnamed: D5.1 (A), R12.2
unnamed: D6.1 (A), R13.2
unnamed: D7.1 (A), R14.2
unnamed: D8.1 (A), R15.2
unnamed: D9.1 (A), R16.2
unnamed: D10.1 (A), R17.2
unnamed: D11.1 (A), R18.2

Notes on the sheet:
Output LED

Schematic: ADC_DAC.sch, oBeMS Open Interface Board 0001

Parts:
C7, C8, C9: 1u; C1_wide_lg_pad_2; Manufacturer Part No Value
P13: ADC_0-7; Pin_Header_Straight_2x08
P14: ADC_8-15; Pin_Header_Straight_2x08
P15: ADC_VREF_2; Pin_Header_Straight_1x02
P16: ADC_VREF_1; Pin_Header_Straight_1x02
P17: SPI_ADC_DAC; Pin_Header_Straight_1x08
P34: DAC; Pin_Header_Straight_2x04
R55, R56, R57: 100k; TH_Resistor_1
U5, U6: MCP3008; DIP-16__300_ELL_lg_pad
U7: MCP4812; DIP-8_300_ELL

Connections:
unnamed: P13.2, U5.1
unnamed: P13.4, U5.2
unnamed: P13.6, U5.3
unnamed: P13.8, U5.4
unnamed: P13.10, U5.5
unnamed: P13.12, U5.6
unnamed: P13.14, U5.7
unnamed: P13.16, U5.8
unnamed: P14.2, U6.1
unnamed: P14.4, U6.2
unnamed: P14.6, U6.3
unnamed: P14.8, U6.4
unnamed: P14.10, U6.5
unnamed: P14.12, U6.6
unnamed: P14.14, U6.7
unnamed: P14.16, U6.8
unnamed: P15.2, U6.15
unnamed: P16.2, U5.15
unnamed 57: P17.2, U5.10; also elsewhere on the board
unnamed 58: P17.3, U6.10; also elsewhere on the board
unnamed: P17.5, U5.11, U6.11, U7.4 (SDI)
unnamed: P17.6, U5.12, U6.12
unnamed: P17.7, U5.13, U6.13, U7.3 (SCLK)
unnamed: P34.1, P34.3, U7.8 (VoutA)
unnamed: P34.5, P34.7, U7.6 (VoutB)

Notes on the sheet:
SPI ADC 8 Channel
SPI DAC 8-Bit Dual
~CS~ PULL UP

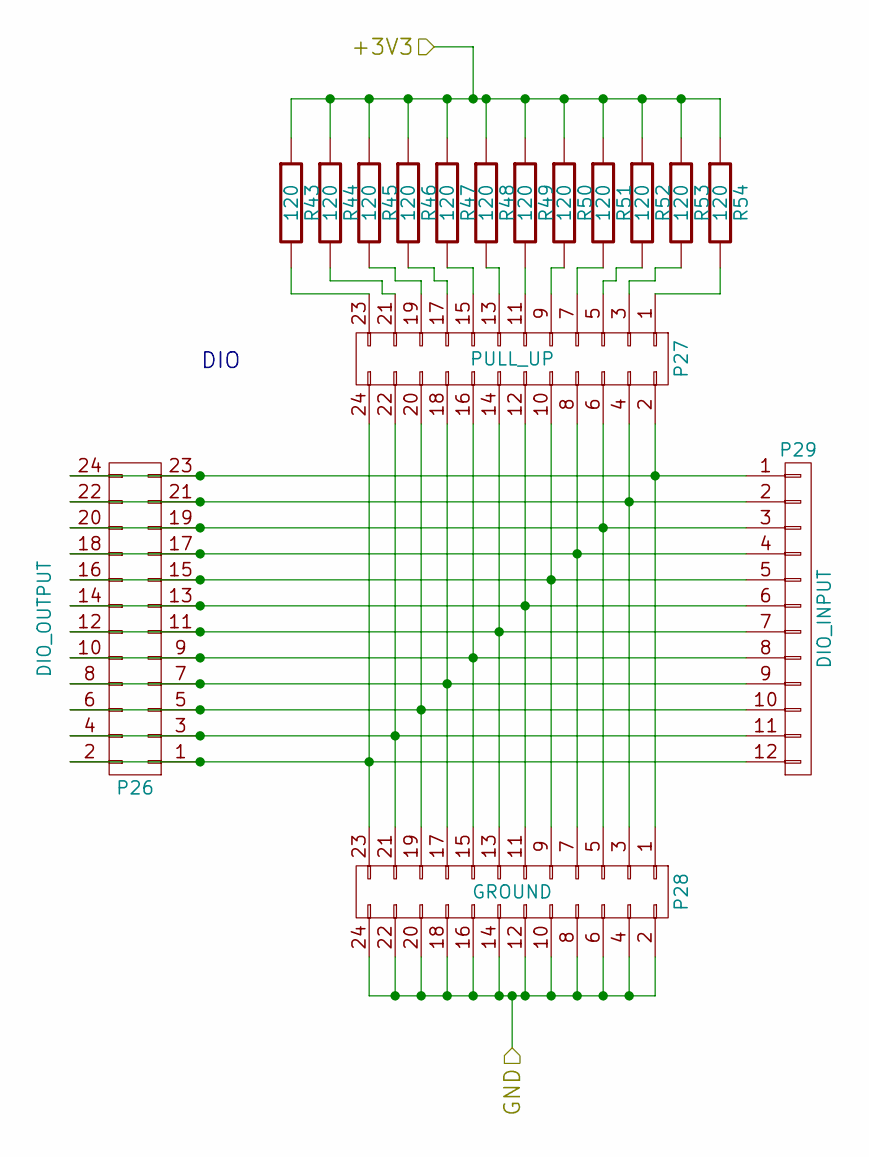
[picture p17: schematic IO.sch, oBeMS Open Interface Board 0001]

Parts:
P18: DIO_OUTPUT; Pin_Header_Straight_2x12
P19: PULL_UP; Pin_Header_Straight_2x12_SM_Connect
P20: GROUND; Pin_Header_Straight_2x12_SM_Connect
P21: DIO_INPUT; HEADER_12Way_Wiedermuller_SX; Manufacturer Part No 1511360000
R19, R20, R21, R22, R23, R24, R25, R26, R27, R28, R29, R30: 120; TH_Resistor_1; Manufacturer Part No Value

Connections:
unnamed: P18.1, P18.2, P19.24, P20.23, P21.12
unnamed: P18.3, P18.4, P19.22, P20.21, P21.11
unnamed: P18.5, P18.6, P19.20, P20.19, P21.10
unnamed: P18.7, P18.8, P19.18, P20.17, P21.9
unnamed: P18.9, P18.10, P19.16, P20.15, P21.8
unnamed: P18.11, P18.12, P19.14, P20.13, P21.7
unnamed: P18.13, P18.14, P19.12, P20.11, P21.6
unnamed: P18.15, P18.16, P19.10, P20.9, P21.5
unnamed: P18.17, P18.18, P19.8, P20.7, P21.4
unnamed: P18.19, P18.20, P19.6, P20.5, P21.3
unnamed: P18.21, P18.22, P19.4, P20.3, P21.2
unnamed: P18.23, P18.24, P19.2, P20.1, P21.1
unnamed: P19.1, R30.2
unnamed: P19.3, R29.2
unnamed: P19.5, R28.2
unnamed: P19.7, R27.2
unnamed: P19.9, R26.2
unnamed: P19.11, R25.2
unnamed: P19.13, R24.2
unnamed: P19.15, R23.2
unnamed: P19.17, R22.2
unnamed: P19.19, R21.2
unnamed: P19.21, R20.2
unnamed: P19.23, R19.2

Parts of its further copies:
P22, P26: DIO_OUTPUT; Pin_Header_Straight_2x12
P23, P27: PULL_UP; Pin_Header_Straight_2x12_SM_Connect
P24, P28: GROUND; Pin_Header_Straight_2x12_SM_Connect
P25, P29, P33: DIO_INPUT; HEADER_12Way_Wiedermuller_SX; Manufacturer Part No 1511360000
R31, R32, R33, R34, R35, R36, R37, R38, R39, R40, R41, R42, R43, R44, R45, R46, R47, R48, R49, R50, R51, R52, R53, R54, R58, R59, R60, R61, R62, R63, R64, R65, R66: 120; TH_Resistor_1; Manufacturer Part No Value

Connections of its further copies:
unnamed: P22.1, P22.2, P23.24, P24.23, P25.12
unnamed: P22.3, P22.4, P23.22, P24.21, P25.11
unnamed: P22.5, P22.6, P23.20, P24.19, P25.10
unnamed: P22.7, P22.8, P23.18, P24.17, P25.9
unnamed: P22.9, P22.10, P23.16, P24.15, P25.8
unnamed: P22.11, P22.12, P23.14, P24.13, P25.7
unnamed: P22.13, P22.14, P23.12, P24.11, P25.6
unnamed: P22.15, P22.16, P23.10, P24.9, P25.5
unnamed: P22.17, P22.18, P23.8, P24.7, P25.4
unnamed: P22.19, P22.20, P23.6, P24.5, P25.3
unnamed: P22.21, P22.22, P23.4, P24.3, P25.2
unnamed: P22.23, P22.24, P23.2, P24.1, P25.1
unnamed: P23.1, R42.2
unnamed: P23.3, R41.2
unnamed: P23.5, R40.2
unnamed: P23.7, R39.2
unnamed: P23.9, R38.2
unnamed: P23.11, R37.2
unnamed: P23.13, R36.2
unnamed: P23.15, R35.2
unnamed: P23.17, R34.2
unnamed: P23.19, R33.2
unnamed: P23.21, R32.2
unnamed: P23.23, R31.2
unnamed: P26.1, P26.2, P27.24, P28.23, P29.12
unnamed: P26.3, P26.4, P27.22, P28.21, P29.11
unnamed: P26.5, P26.6, P27.20, P28.19, P29.10
unnamed: P26.7, P26.8, P27.18, P28.17, P29.9
unnamed: P26.9, P26.10, P27.16, P28.15, P29.8
unnamed: P26.11, P26.12, P27.14, P28.13, P29.7
unnamed: P26.13, P26.14, P27.12, P28.11, P29.6
unnamed: P26.15, P26.16, P27.10, P28.9, P29.5
unnamed: P26.17, P26.18, P27.8, P28.7, P29.4
unnamed: P26.19, P26.20, P27.6, P28.5, P29.3
unnamed: P26.21, P26.22, P27.4, P28.3, P29.2
unnamed: P26.23, P26.24, P27.2, P28.1, P29.1
unnamed: P27.1, R54.2
unnamed: P27.3, R53.2
unnamed: P27.5, R52.2
unnamed: P27.7, R51.2
unnamed: P27.9, R50.2
unnamed: P27.11, R49.2
unnamed: P27.13, R48.2
unnamed: P27.15, R47.2
unnamed: P27.17, R46.2
unnamed: P27.19, R45.2
unnamed: P27.21, R44.2
unnamed: P27.23, R43.2

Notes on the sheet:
DIO

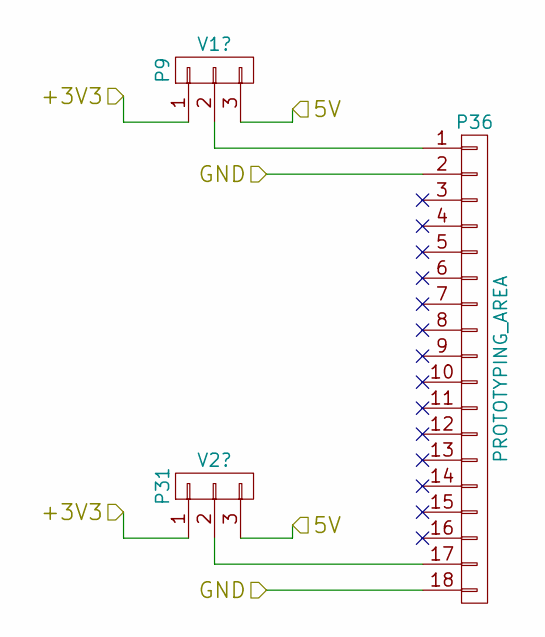
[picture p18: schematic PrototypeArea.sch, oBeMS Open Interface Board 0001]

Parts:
P9: V1?; SIL-3_solder_connect
P31: V2?; SIL-3_solder_connect
P36: PROTOTYPING_AREA; PROTO_AREA_16x14

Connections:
+5V: P9.3, P31.3; also elsewhere on the board
unnamed: P31.2, P36.17
unnamed: P9.2, P36.1

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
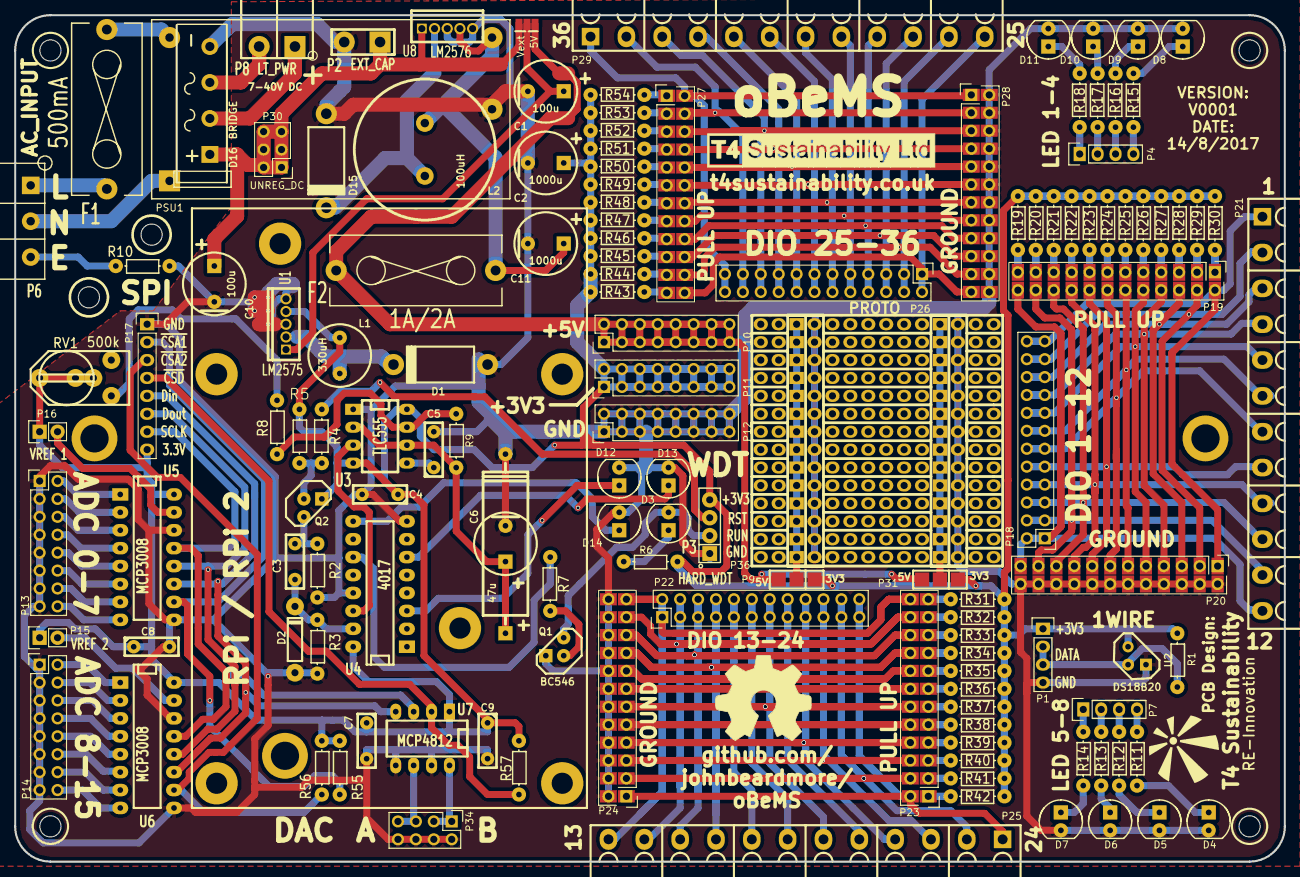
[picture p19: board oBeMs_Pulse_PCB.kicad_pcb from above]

Board: 2 copper layers, 180.0 x 120.0 mm, 140 parts (0 on the bottom side), 147 nets.

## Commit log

2015-10-06 Initial commit of PCB Schematic
    [oBeMs_Pulse_PCB.sch]
2015-10-12 Update Schematic and add presentation
    [oBeMs_Pulse_PCB.sch]
2015-10-22 Update Schematic WDT and PSU
    [oBeMs_Pulse_PCB.sch]
2015-11-04 Update to initial version of PCB
    Initial PCB version.
    [ADC.sch, ADC_DAC.sch, IO.sch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]
2015-11-09 Update PCB
    With notes from John
    [PSU.sch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]
2015-12-17 Version 3 revision
    Added 3A switching 5V supply and Capacitors axial and radial
    [ADC_DAC.sch, IO.sch, LED.sch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]
2015-12-19 Updated small changes.
    Info and changes from email 18/12/15.
    [oBeMs_Pulse_PCB.kicad_pcb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]
2015-12-20 Small changes on PCB
    [oBeMs_Pulse_PCB-B.Cu.gbr, oBeMs_Pulse_PCB-B.Mask.gbr, oBeMs_Pulse_PCB-B_Cu.gbr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]
2015-12-21 Updates from email 21/12/15
    [ADC_DAC.sch, IO.sch, LED.sch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]
2015-12-22 More small changes 22/12/15
    [ADC_DAC.sch, IO.sch, PSU.sch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]
2015-12-23 Rev 6. Final changes before PCB v0000 done
    [ADC_DAC.sch, IO.sch, LED.sch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]
2017-08-14 Changes for v0001
    Multiple PCb changes. 50Pcs ordered
    [ADC_DAC.sch, IO.sch, LED.sch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]
